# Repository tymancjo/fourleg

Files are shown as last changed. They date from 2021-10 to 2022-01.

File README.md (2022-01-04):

# FLR „Aron”

# Mk2 is on the way

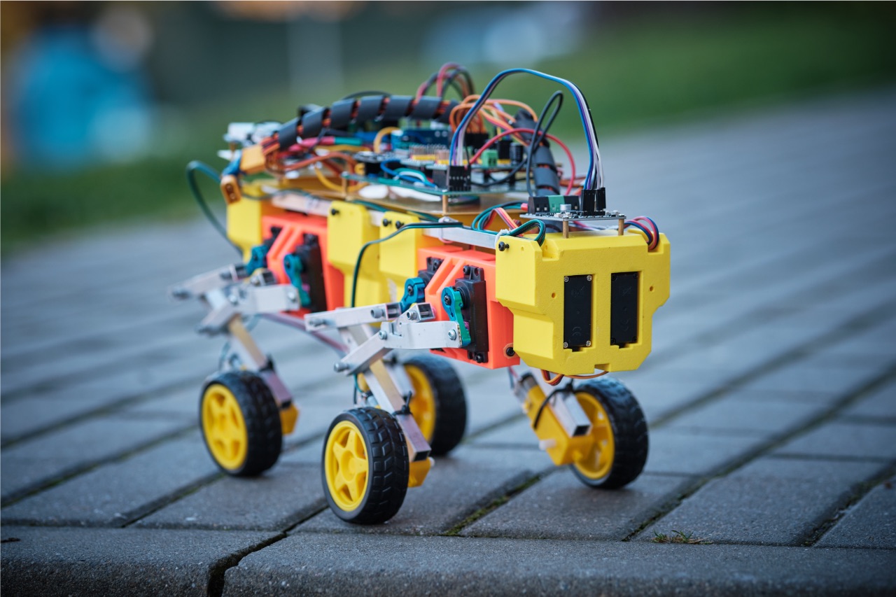
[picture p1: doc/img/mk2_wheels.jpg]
Aron Mk2
Currently a new version is in the development, hence all the code and data for the mk1 were moved ot the mk1 folder. 

## Mk2 idea

The main idea behind the mk2 is to add the 3th DOF for the leg. It is made by use of one additional servo for each leg. It is now heavily based on the 3d printed parts.

## Mechanical model

The - not so fully finished - 3d model made in Fusion 360 is available in the **3D_model** folder. It covers all the required geometry in the form that was used for the build.

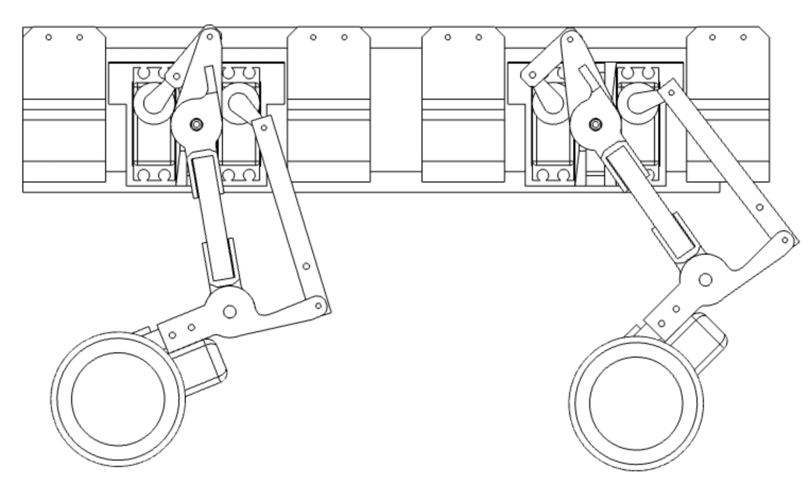
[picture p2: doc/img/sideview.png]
Aron sketch


However some leg parts need to be printed as they are and as a mirrored ones - for the other side.
As this project will move forward - the model will be updated to the full one.

Additionally all STL files (for both sides left and right) that were used for printing and build are in the **3D_model/STL** folder.

## General BOM

To build the Aron the following components are needed:

- The 3D printed parts

  - 2x End Mount
  - 2x Middle Support
  - 4x Leg Bracket
  - Knee LR x2
  - Motor R x2
  - Motor L x2
  - Top LR x2

- The ESP32 as a main control unit
- 2x PCA9685 to control the servos
- DC/DC converter for powering servo
- DC/DC converter for the electronic
- 2 channel H control for the DC motors
- BLT 05 BlueTooth unit

## The firmware

The main piece of software that is controlling the Aron is the **mk2_firmware** located in the **Arduino** folder.

## The interface

The Aron Mk2 in basic level can be controlled by the set of serial commands.
Those can be sent to the ESP32 main UART via either the USB connection of the module or via the used BT module.

For the convenience and ease of use additional layer in form of Web Control Interface is added. It is made out of two main interfaces - the Jog and the WebSerial.

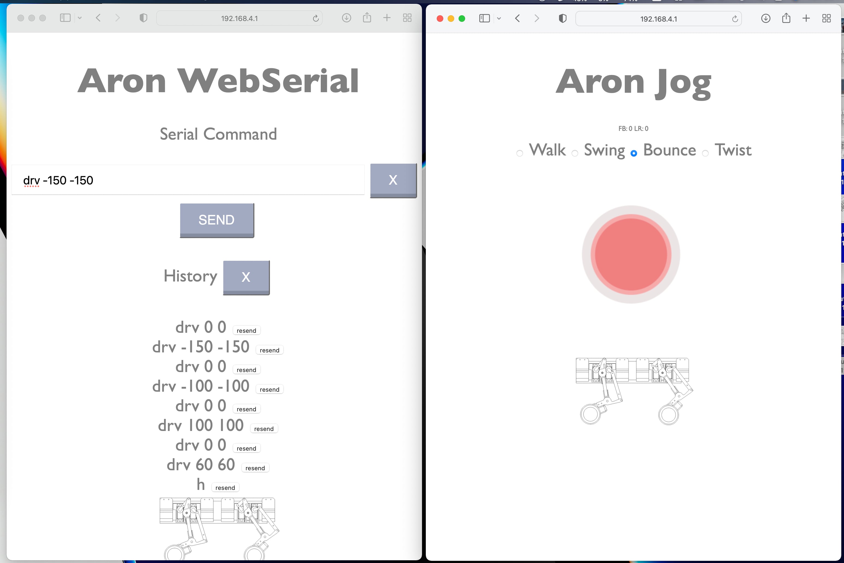
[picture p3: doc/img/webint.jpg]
web interfaces


### The Aron Jog

This interface is aimed for a real time remote control and allows to use the on screen joy to set live the behavior for:

- Walking around
- Swinging front and sideways
- Bounce up down
- Twist around.

This interface is available under:

> http://ARON_PI/

### The WebSerial

This is a basic web to serial transciver.
Works the same way as sending the serial commands directly via UART or BLE. Just is is available a sa webpage under:

> http://ARON_IP/serial

## Available Commands

At this stage the supported commands are:

- test // run the simple test sequence - just moves all servos in loop.
- power // toggle the power out
- show // displaying back the current angles of all servos

- h // resetting the servos to home position
- reset // resetting the servos home to initial position - but no move make
- ramp XXX // set up the ramp value input as 990 gives 0.99 ramp etc.

- circ XX YY // moving front back (XX) left right(YY) by 2 arguments
- move // triggering to make move to current incremental set
- up FF BB // lowering or rising front (FF) and back (BB) legs by given value (-40 to 40)
- leg L FF UP 0 // set data for single leg incremental model move - L leg number (1,2,3 or 4)
- drv LLL RRR // move the wheels by 2 params in range -255 to 255 (0 is strop) for Left (LLL) and Right (RRR) wheels
- s // full stop for wheels
- twist TT // twist - to make twisted pose - param in range -50 to 50
- walk // the sudo walk command
- w // the sudo walk command
- fake // to test the fake serial data

## Lastly:

> This is a work in progress project...

If you are interested please take a look at the vide playlist:
[YouTube Playlist](https://www.youtube.com/watch?v=CJRxDc_nvHY&list=PL9g9iwA2sCQyebAMLQ3WOS7w4_cqAUxdq)

#

#

# Original info about Aron Mk1

## Intro

FLR as Four Leg Robot - is a hobby project aimed for experimenting with the idea of simple and affordable four leg robot build. It’s a playground for self study of the basic ideas of kinetic, stability and more.

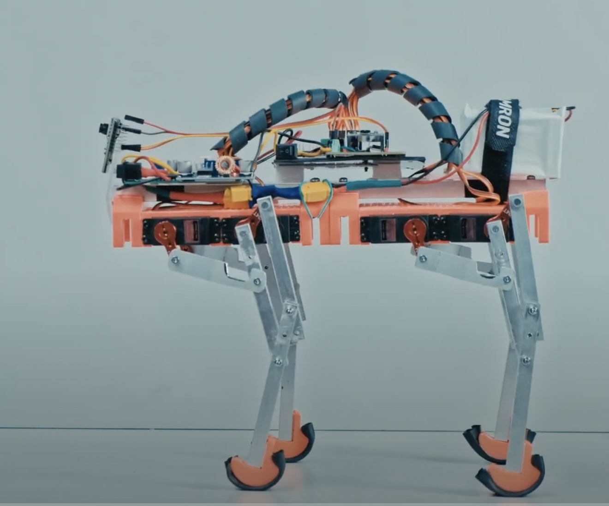
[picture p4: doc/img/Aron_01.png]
Aron


## More info

There is a set of videos - mostly in polish abut Aron and other robotic projects of mine.

YT (https://www.youtube.com/watch?v=iG_khF_uAIs&list=PL9g9iwA2sCQyebAMLQ3WOS7w4_cqAUxdq)

## Hardware

Hardware is based on the generally available parts and some simple 3D prints. The 3D model made in Autodesk Fusion 360 is available to download in the „Mechanical_Model” folder of this directory.

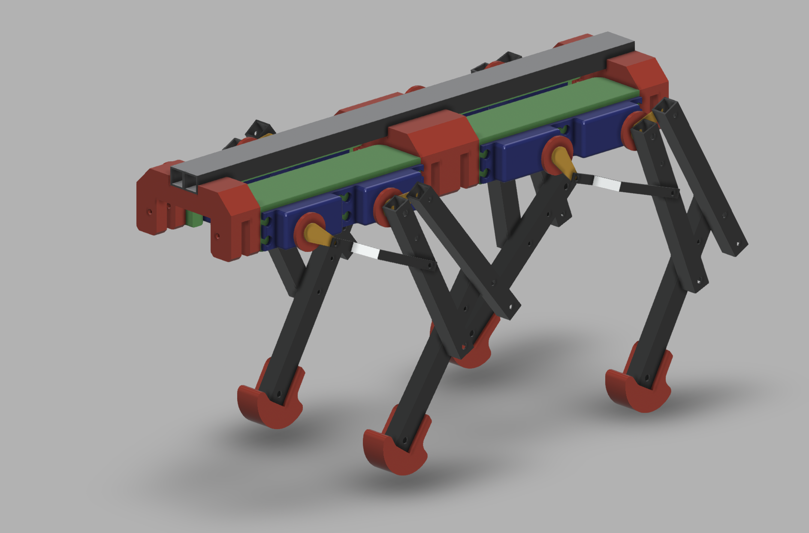
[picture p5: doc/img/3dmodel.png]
3D model


[fourleg/Mechanical_Model at main · tymancjo/fourleg · GitHub](https://github.com/tymancjo/fourleg/tree/main/Mechanical_Model)

And a 3d visualization under the link:
https://gmail1957699.autodesk360.com/g/shares/SH35dfcQT936092f0e43c23261b81addf43c

Beside the mechanicals the main components are MG995 180 degree servos (or in general any servo of the similar size and torque) , the PCA9685 16-Channel 12-bit PWM/Servo Driver to drive them and and esp32 as a main controller of the system. But the main controller role can be covered as well by Arduino board of generally any kind.

Power source is made of the 2S2P set of 18650 Li-Ion cells with appropriate BMS system followed by 2 independent DC/DC converters that are stabilizing the voltage at 5V for servos (the V+ power on the PCA9685) and another 5V for the esp32.

In the prototype unit additionally an esp32cam is installed enabling some experiments possibility with simple computer vision. However it’s not a crucial element of the system.

## Software

The software is created in the Arduino IDE environment and utilize the supporting libraries from Adafruit and other ESP32 related ones.
The main firmware file is the „esp32_servo_from_uart_WiFi” sketch located in the Arduino folder.

[fourleg/Arduino at main · tymancjo/fourleg · GitHub](https://github.com/tymancjo/fourleg/tree/main/Arduino)

Separate software is available for the esp32cam module - and it is based on the available esp32cam example sketch delivered with the word manager resources.

Additionally some python helper programs are available - mostly used for plying around with preparing Aron poses and move sequences.

## Usage

There are two main ways to control the Aron behavior.
Firstly by the webpage.

### Webpage interface

When powered up the esp32 main unit setup a WiFi access point by a name BB.LAB.ARON and pass 123456789 (yeap! the super secure one). When connected to this network - an webpage is available under 192.168.1.1 IP address from where the pre-programmed behavior can be controlled by use of buttons.
It’s extreakly simple interface and shall be quite self explanatory.

### Serial (UART)

The other way of control is via the UART (serial port) communication to the main esp32. The transmission is set up tu go with the 115200 baud rate. But all of this can be modified in the firmware.

The way to send orders is to use the following string scheme:

> <C,s1,s2,s3,s4,s5,s6,s7,s8>

Where:
C - is the command id
And the s1 to s8 are parameters.

The main commands are:
42 - makes the servos set up to the given angles where s1 to s8 are servo angles.

44 - recall one of the stored positions, where s1 is the number of position (counting from 0), s2 to s8 need to be set to some value (any).

46 - plays saved sequence, where s1 is the sequence number, and the s2 is number of repetition (1 to 20). S3 to s8 need to be set to any number.

55 - saves the servos as new stored position taking the given angles where s1 to s8 are servo angles.

#### Servos numbering

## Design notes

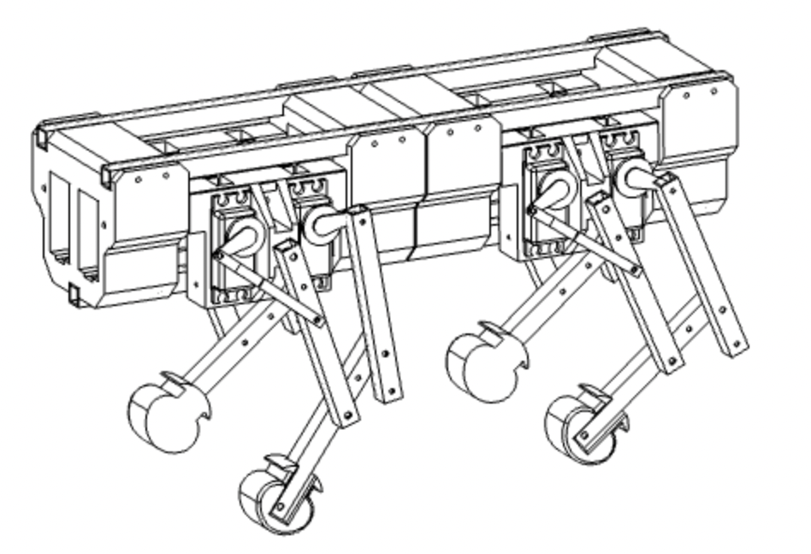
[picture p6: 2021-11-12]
Python/img/aronmk2.png

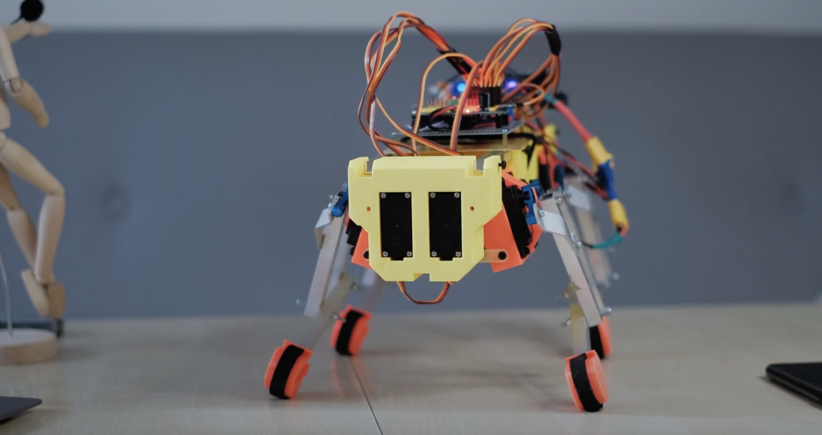
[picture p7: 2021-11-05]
doc/img/mk2.png

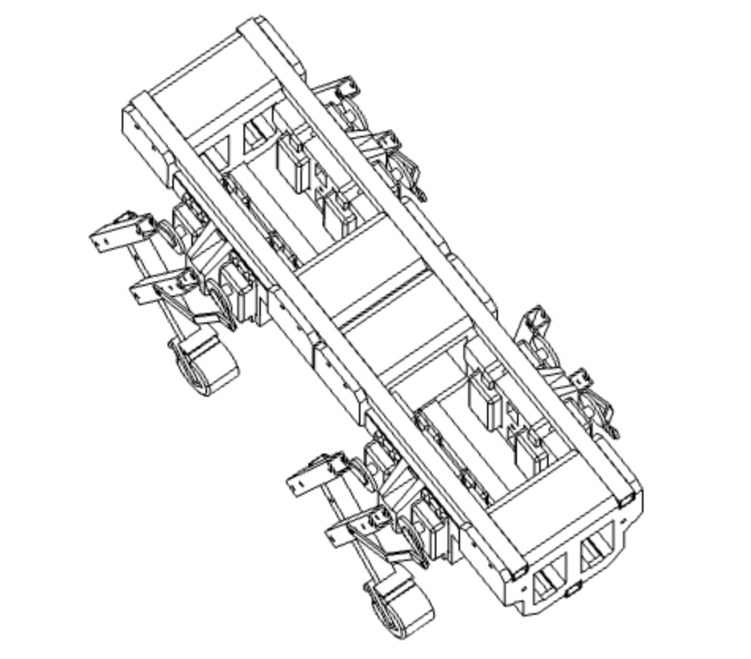
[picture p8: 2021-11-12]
Python/img/aronmk2T.png

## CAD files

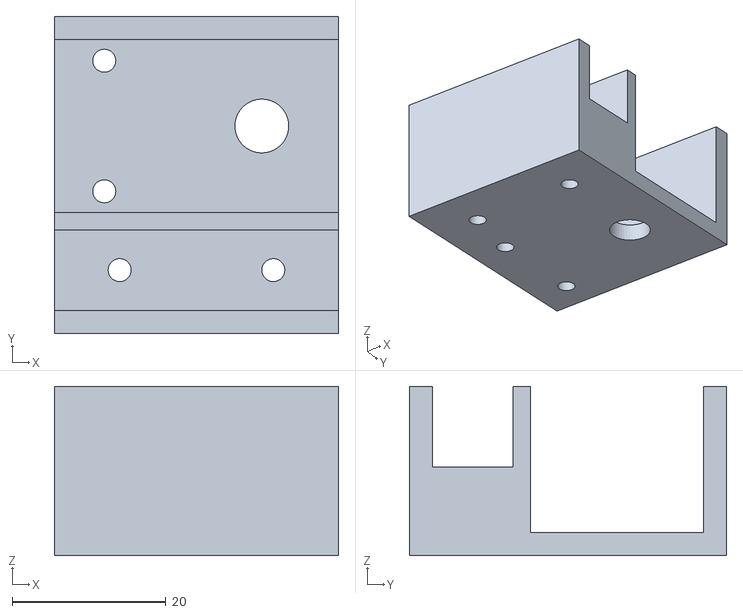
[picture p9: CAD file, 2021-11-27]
3D_model/STL/mk2_motor_L_2szt.stl
37.0 x 41.2 x 22.0

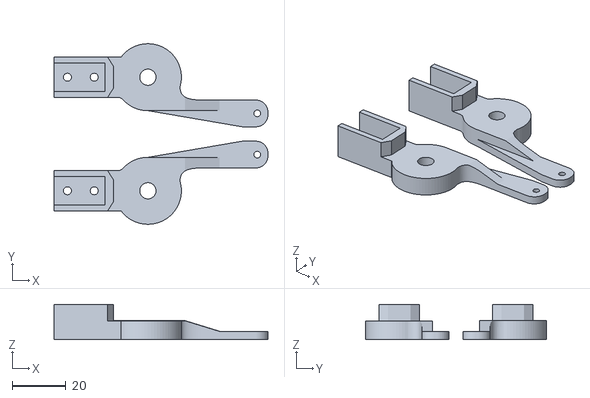
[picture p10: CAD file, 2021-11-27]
3D_model/STL/mk2_knee_LR_po_2szt.stl
79.8 x 67.3 x 13.1

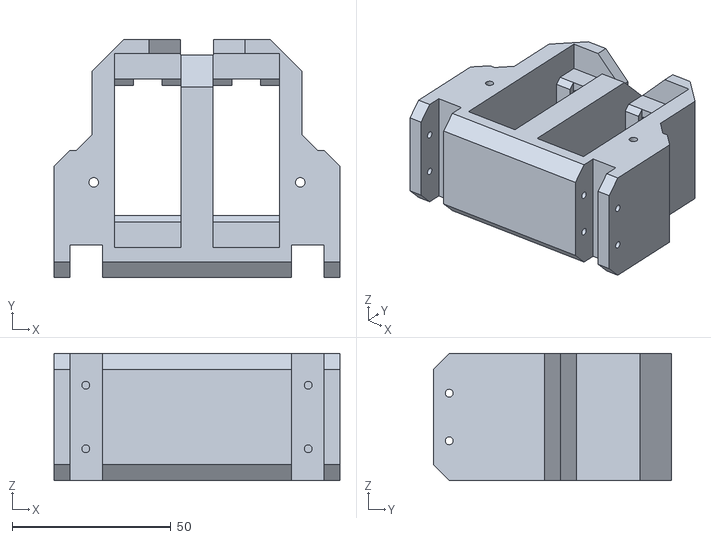
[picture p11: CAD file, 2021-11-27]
3D_model/STL/AronMk2EndMount_2szt.stl
90.0 x 75.0 x 40.0

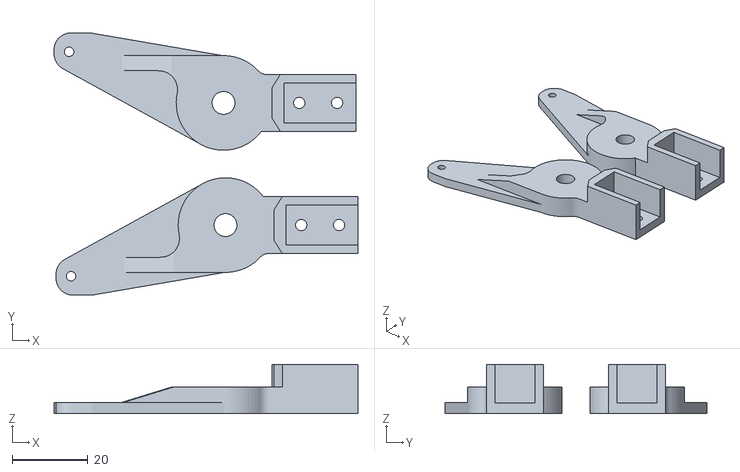
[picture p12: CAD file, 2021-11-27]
3D_model/STL/mk2_top_LR_po_2szt.stl
80.3 x 69.3 x 13.0

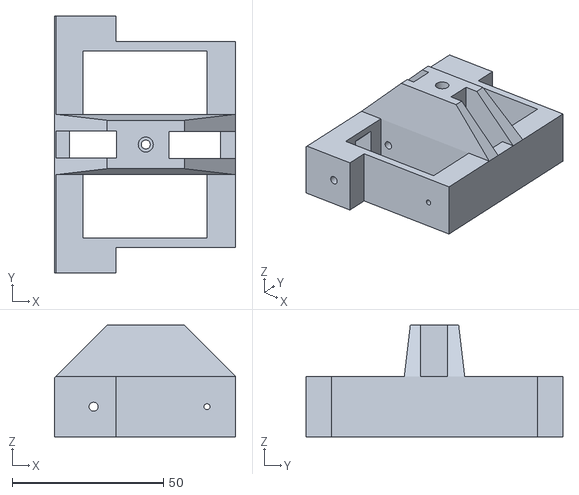
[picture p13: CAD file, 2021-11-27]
3D_model/STL/LegBracketMk2_V1_3szt.stl
60.0 x 85.0 x 37.0

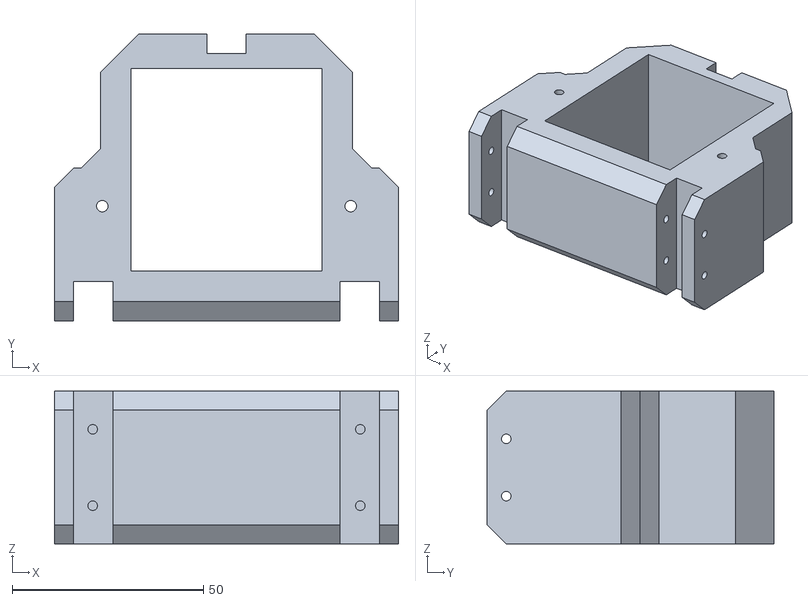
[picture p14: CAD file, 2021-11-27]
3D_model/STL/AronMk2MiddleSupport_2szt.stl
90.0 x 75.0 x 40.0

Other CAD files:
3D_model/STL/mk2_motor_R_2szt.stl
3D_model/Arom_Mk2_v1_v17.f3z
AronMk1/Mechanical_Model/flr_aron_mk1_v8.f3z

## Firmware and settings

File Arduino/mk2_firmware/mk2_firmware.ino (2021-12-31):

/*************************************************** 
  This is based on the example for our Adafruit 16-channel PWM & Servo driver
  Servo test - this will drive servos using  the PCA9685

  Pick one up today in the adafruit shop!
  ------> http://www.adafruit.com/products/815
  
  These drivers use I2C to communicate, 2 pins are required to  
  interface.

  Adafruit invests time and resources providing this open source code, 
  please support Adafruit and open-source hardware by purchasing 
  products from Adafruit!

  Written by Limor Fried/Ladyada for Adafruit Industries.  
  BSD license, all text above must be included in any redistribution
 ****************************************************/

#include <Wire.h>
#include <Adafruit_PWMServoDriver.h>

#include "SerialCommand.h"
SerialCommand sCmd; // The SerialCommand object

#include <WiFi.h>
#include <AsyncTCP.h>
#include <ESPAsyncWebServer.h>
// #include <ArduinoJson.h>

// to be able use filesystem
#include "FS.h"
#include "SPIFFS.h"

#include "secret.h"

// the credentials comes from the secret.h file
const char *ssid = SSIDs;
const char *password = PASSs;

// ********** Stuff for webservice *********

// Create AsyncWebServer object on port 80
AsyncWebServer server(80);
AsyncWebSocket ws("/ws");

void notifyClients()
{
  // I don't use anyting to be send back
}

void handleWebSocketMessage(void *arg, uint8_t *data, size_t len)
{
  AwsFrameInfo *info = (AwsFrameInfo *)arg;
  if (info->final && info->index == 0 && info->len == len && info->opcode == WS_TEXT)
  {
    data[len] = 0;
    command((char *)data);
  }
}

void onEvent(AsyncWebSocket *server, AsyncWebSocketClient *client, AwsEventType type,
             void *arg, uint8_t *data, size_t len)
{
  switch (type)
  {
  case WS_EVT_CONNECT:
    Serial.printf("WebSocket client #%u connected from %s\n", client->id(), client->remoteIP().toString().c_str());
    break;
  case WS_EVT_DISCONNECT:
    Serial.printf("WebSocket client #%u disconnected\n", client->id());
    break;
  case WS_EVT_DATA:
    handleWebSocketMessage(arg, data, len);
    break;
  case WS_EVT_PONG:
  case WS_EVT_ERROR:
    break;
  }
}

void initWebSocket()
{
  ws.onEvent(onEvent);
  server.addHandler(&ws);
}

String processor(const String &var)
{
  Serial.println(var);
  return "OK";
}

// ******************

// Setting up the PCA9685 units
Adafruit_PWMServoDriver pwm = Adafruit_PWMServoDriver(0x40);
Adafruit_PWMServoDriver pwm2 = Adafruit_PWMServoDriver(0x60);

// Depending on your servo make, the pulse width min and max may vary, you
// want these to be as small/large as possible without hitting the hard stop
// for max range. You'll have to tweak them as necessary to match the servos you
//// have!

#define SERVOMIN 170  // This is the 'minimum' pulse length count (out of 4096)
#define SERVOMAX 495  // This is the 'maximum' pulse length count (out of 4096)
#define SERVO_FREQ 50 // Analog servos run at ~50 Hz updates

// setting up the variabes for the servos
uint8_t servonum = 0;
const uint8_t servos = 16;
uint8_t servo_delay = 20;
uint8_t servos_steps_amount = 30;

// float servo_zero[servos]    = {   90,90,90,90,  90,90,90,90,  90,90,90,90,  90,90,90,90 };
// float servo_target[servos]  = {   90,90,90,90,  90,90,90,90,  90,90,90,90,  90,90,90,90 };
// float servo_home[servos]    = {   90,90,90,90,  90,90,90,90,  90,90,90,90,  90,90,90,90 };

float servo_zero[servos] = {90, 90, 90, 90, 90, 90, 90, 90, 110, 70, 110, 70, 90, 90, 90, 90};
float servo_target[servos] = {90, 90, 90, 90, 90, 90, 90, 90, 110, 70, 110, 70, 90, 90, 90, 90};
float servo_home[servos] = {90, 90, 90, 90, 90, 90, 90, 90, 110, 70, 110, 70, 90, 90, 90, 90};
bool servo_inverse[servos] = {0, 0, 1, 1, 0, 0, 1, 1, 0, 0, 1, 1, 0, 0, 0, 0};

// for making the incremental model
float servo_up[servos] = {0, 0, 0, 0, 0, 0, 0, 0, 0, 0, 0, 0, 0, 0, 0, 0};
float servo_side[servos] = {0, 0, 0, 0, 0, 0, 0, 0, 0, 0, 0, 0, 0, 0, 0, 0};
float servo_fb[servos] = {0, 0, 0, 0, 0, 0, 0, 0, 0, 0, 0, 0, 0, 0, 0, 0};
float servo_lr[servos] = {0, 0, 0, 0, 0, 0, 0, 0, 0, 0, 0, 0, 0, 0, 0, 0};
float servo_legs[servos] = {0, 0, 0, 0, 0, 0, 0, 0, 0, 0, 0, 0, 0, 0, 0, 0};

float servo_current[servos] = {150, 90, 150, 90, 150, 90, 150, 90, 90, 90, 90, 90, 0, 0, 0, 0};
float servo_ramp[servos];
float servo_step[servos] = {2, 2, 2, 2, 2, 2, 2, 2, 2, 2, 2, 2, 2, 2, 2, 2};

bool move_done = false;
bool in_loop = false;
bool in_linear = true;
int waiting = 0;

unsigned long now = millis();
unsigned long last = millis();
unsigned long last_step = millis();
unsigned long idle_time = millis();
unsigned long rand_sequence_time = millis();
int idle_moves = 0;
int idle_delay = 15000;
bool use_random = true;
bool in_random_sequence = false;
bool last_rand = false;
bool last_rand_walk = true;
bool last_rand_walk2 = true;

#define LEDPIN 2
#define POWEROUT 12

#define M1A 33
#define M1B 25
#define M2A 26
#define M2B 27

// #define DEBUG
#ifdef DEBUG
#define DEBUG_PRINT(x) Serial.print(x)
#define DEBUG_PRINTLN(x) Serial.println(x)
#else
#define DEBUG_PRINT(x)
#define DEBUG_PRINTLN(x)
#endif

bool power = false;

void setup()
{
  //  Serial.begin(115200);
  Serial.begin(9600);
  Serial.println("Aron mk2 Firmware System");
  pinMode(LEDPIN, OUTPUT);
  pinMode(POWEROUT, OUTPUT);

  // Preparing the PWM channels for the motors
  ledcAttachPin(M1A, 0); // assign a led pins to a channel
  ledcAttachPin(M1B, 1); // assign a led pins to a channel
  ledcAttachPin(M2A, 2); // assign a led pins to a channel
  ledcAttachPin(M2B, 3); // assign a led pins to a channel

  ledcSetup(0, 4000, 8); // 12 kHz PWM, 8-bit resolution
  ledcSetup(1, 4000, 8); // 12 kHz PWM, 8-bit resolution
  ledcSetup(2, 4000, 8); // 12 kHz PWM, 8-bit resolution
  ledcSetup(3, 4000, 8); // 12 kHz PWM, 8-bit resolution

  digitalWrite(POWEROUT, power);

  // Setup callbacks for SerialCommand command

  sCmd.addCommand("test", runTest);       // run the  test sequence - just moves all servos in loop.
  sCmd.addCommand("back", runBack);       // run the  test sequence - just moves all servos in loop.
  sCmd.addCommand("save", saveStep);      // adding current position as new step in selected sequence
  sCmd.addCommand("del", delLastStep);    // removing last step from given sequence
  sCmd.addCommand("power", togglePower);  // toggle the power out
  sCmd.addCommand("show", showAngles);    // displaying back the current angles of all servos
  sCmd.addCommand("write", saveToFile);   // saving the sequences to file
  sCmd.addCommand("read", loadFromFile);  // load the sequences form file
  sCmd.addCommand("load", loadFromFile2); // load the sequences form file

  sCmd.addCommand("h", makeHoming);   // ressetting the servos to home position
  sCmd.addCommand("reset", makeZero); // ressetting the servos home to initial position - but no move make
  sCmd.addCommand("ramp", setRamp);   // set up the ramp value input as 990 gives 0.99 ramp etc.

  sCmd.addCommand("circ", makeCircle); // moving front back left right by 2 arguments
  sCmd.addCommand("move", makeMove);   // triggering to make the move to current incremental set
  sCmd.addCommand("up", makeUp);       // adding the value to the homing of the up/dn servos
  sCmd.addCommand("side", makeSide);   // the left right leveling
  sCmd.addCommand("leg", moveLeg);     // set data for single leg incremental model move
  sCmd.addCommand("drv", driveWheels); // move the wheels by 2 params
  sCmd.addCommand("s", allStop);       // full stop for wheels
  sCmd.addCommand("twist", makeTwist); // twist - to make a turning - experimental
  sCmd.addCommand("walk", makeWalk);   // the sudo walk command
  sCmd.addCommand("w", makeWalk);      // the sudo walk command
  sCmd.addCommand("look", lookAround); // looking around in LR TD

  sCmd.addCommand("fake", fakeData);       // to test the fake serial data
  sCmd.addCommand("mode", toogleMmode);    // toggle the interpoloation mode
  sCmd.addCommand("random", toogleRandom); // toggle random behaviour
  sCmd.addCommand("step", setStepSize);    // to set the single step size in degrees
  sCmd.addCommand("delay", setDelay);      // to set the each loop servos delay

  sCmd.addCommand("setraw", setAllServosRaw); // kind of the backdoor function to set all servos
  sCmd.addCommand("list", listSequences);     // listing the current sequences to serial port

  // sCmd.addCommand("s", setServo);             // set a single servo command
  // sCmd.addCommand("d", setServoDelta);        // set a single servo by delta angle command
  // sCmd.addCommand("ad", setAllServosDelta);   // move all by individual deltas
  // sCmd.addCommand("adh", setAllServosDeltaHome);  // move all by individual deltas from home position

  sCmd.setDefaultHandler(unrecognized); // Handler for command that isn't matched  (says "What?")

  // preparing the inital positions.
  for (int k = 0; k < servos; k++)
  {
    set_servo(k, servo_current[k]);
    servo_ramp[k] = 0.95;
  }

  // kicking off the PCA units
  pwm.begin();
  pwm2.begin();

  /*
   * In theory the internal oscillator (clock) is 25MHz but it really isn't
   * that precise. You can 'calibrate' this by tweaking this number until
   * you get the PWM update frequency you're expecting!
   * The int.osc. for the PCA9685 chip is a range between about 23-27MHz and
   * is used for calculating things like writeMicroseconds()
   * Analog servos run at ~50 Hz updates, It is importaint to use an
   * oscilloscope in setting the int.osc frequency for the I2C PCA9685 chip.
   * 1) Attach the oscilloscope to one of the PWM signal pins and ground on
   *    the I2C PCA9685 chip you are setting the value for.
   * 2) Adjust setOscillatorFrequency() until the PWM update frequency is the
   *    expected value (50Hz for most ESCs)
   * Setting the value here is specific to each individual I2C PCA9685 chip and
   * affects the calculations for the PWM update frequency. 
   * Failure to correctly set the int.osc value will cause unexpected PWM results
   */
  pwm.setOscillatorFrequency(27000000);
  pwm.setPWMFreq(SERVO_FREQ); // Analog servos run at ~50 Hz updates

  pwm2.setOscillatorFrequency(27000000);
  pwm2.setPWMFreq(SERVO_FREQ); // Analog servos run at ~50 Hz updates

  // checking the file system
  if (!SPIFFS.begin(true))
  {
    Serial.println("An Error has occurred while mounting SPIFFS");
    return;
  }

  // Preparing static IP adress
  IPAddress local_ip0(192, 168, 0, 123);
  IPAddress gateway0(192, 168, 0, 1);
  IPAddress subnet0(255, 255, 255, 0);

  // Connect to Wi-Fi
  if (!WiFi.config(local_ip0, gateway0, subnet0))
  {
    Serial.println("STA Failed to configure");
  }

  WiFi.begin(ssid, password);
  int wifitrys = 0;
  while (WiFi.status() != WL_CONNECTED)
  {
    delay(1000);
    Serial.println("Connecting to WiFi..");
    wifitrys++;

    if (wifitrys > 7)
      break;
  }
  delay(300);

  // if not connected - making own AP
  if (WiFi.status() != WL_CONNECTED)
  {
    WiFi.disconnect();

    delay(1000);
    // setting up self WiFi
    const char *ssid2 = "BB.LAB.ARON";
    const char *password2 = "123456789";

    /* Put IP Address details */
    IPAddress local_ip(192, 168, 1, 1);
    IPAddress gateway(192, 168, 1, 1);
    IPAddress subnet(255, 255, 255, 0);

    Serial.print("Setting AP (Access Point)…");
    WiFi.softAP(ssid2, password2);
    WiFi.softAPConfig(local_ip, gateway, subnet);
    delay(300);
    Serial.println(WiFi.softAPIP());
  }
  else
  {
    // Print ESP Local IP Address
    Serial.println(WiFi.localIP());
  }

  initWebSocket();

  // Route for root / web page
  server.on("/", HTTP_GET, [](AsyncWebServerRequest *request)
            { request->send(SPIFFS, "/index.html", "text/html"); });

  server.on("/serial", HTTP_GET, [](AsyncWebServerRequest *request)
            { request->send(SPIFFS, "/serial.html", "text/html"); });

  server.on("/img", HTTP_GET, [](AsyncWebServerRequest *request)
            { request->send(SPIFFS, "/aronmk2.jpg", "image/jpeg"); });

  // Start server
  server.begin();

  Serial.print("Starting up");
  for (int k = 0; k < 21; k += 4)
  {
    digitalWrite(LEDPIN, HIGH);
    Serial.print(".");
    delay(400 - k * 20);
    digitalWrite(LEDPIN, LOW);
    delay(400 - k * 20);
  }
  Serial.println();
  digitalWrite(LEDPIN, HIGH);
  loadFromFile2(); // loading the stored in file move sequences
}

// simple loop moving test - usefull for hardware verification.
const int sequences = 10; // the total numbeer of available sequences
const int max_steps = 30; // the max number of steps in each sequence
int test_step = 0;        // the step counter for seq playback
uint8_t set_sequence = 0; // the selected sequence for playback
int seq_direction = 1;    // its 1 or -1 is the step by which the seq is proceed
uint8_t test_steps[sequences] = {2, 0, 0, 0, 0, 0, 0, 0, 0, 0};
uint8_t seq_repetitions = 50;
uint8_t this_repetitions = 0;

// this is the hardcoded move sequence used for walk command
uint8_t test_pos[sequences][max_steps][servos] = {
    {// first sequence
     {70, 70, 110, 110, 110, 110, 70, 70, 140, 80, 90, 40, 90, 90, 90, 90},
     {110, 110, 70, 70, 70, 70, 110, 110, 100, 40, 130, 80, 90, 90, 90, 90}}};

void loop()
{
  // marking current time
  now = millis();
  // making the read from serial
  sCmd.readSerial();
  // checking the `webSocket stuff
  ws.cleanupClients();

  // playing the storred sequence
  if (now > last_step + 100 && move_done && in_loop && test_steps[set_sequence] > 0 && this_repetitions < seq_repetitions)
  {
    last_step = now;
    idle_time = now;

    DEBUG_PRINT(set_sequence);
    DEBUG_PRINT(':');
    DEBUG_PRINT(test_step);
    DEBUG_PRINTLN();

    for (int s = 0; s < servos; s++)
    {
      servo_target[s] = test_pos[set_sequence][test_step][s];
    }
    test_step += seq_direction;
    move_done = false;
    getStepSize();

    if (test_step >= test_steps[set_sequence])
    {
      test_step = 0;
      this_repetitions++;
    }
    if (test_step < 0)
    {
      test_step = test_steps[set_sequence] - 1;
      this_repetitions++;
    }
  } // end of servo sequence play

  if (this_repetitions >= seq_repetitions)
  {
    drive(0, 0);
  }

  // checking for standing still too long
  if (now > idle_time + idle_delay && use_random)
  {
    uint8_t selector = random(0, 100);
    if (selector > 30)
    {
      idle_moves++;
      if (idle_moves < 10)
      {
        idle_delay = random(1000, 4000);
      }
      else
      {
        idle_delay = random(8000, 20000);
        idle_moves = 0;
      }

      int look_x = random(0, 40) - 20;
      int look_y = random(0, 60) - 15;
      char chars[32];

      sprintf(chars, "look %d %d\n", look_x, look_y);
      command(chars);
    }
    else if (selector > 20)
    {
      in_random_sequence = true;
      idle_delay = random(4000, 9000);
      rand_sequence_time = now;
      idle_time = now;

      if (last_rand_walk)
      {
        command("test 2\n");
      }
      else
      {
        command("back 2\n");
      }
      last_rand_walk = !last_rand_walk;
    }
    else if (selector > 10)
    {
      in_random_sequence = true;
      idle_delay = random(6000, 11000);
      rand_sequence_time = now;
      idle_time = now;

      if (last_rand_walk)
      {
        command("test 3\n");
      }
      else
      {
        command("back 3\n");
      }
      last_rand_walk2 = !last_rand_walk2;
    }
    else
    {
      // if selector is <10
      // we will turn l/r
      in_random_sequence = true;
      idle_delay = random(2000, 4000);
      rand_sequence_time = now;
      idle_time = now;
      if (last_rand)
      {
        command("w 0 110\n");
      }
      else
      {
        command("w 0 -110\n");
      }
      last_rand = !last_rand;
    }
  }

  // stoping random seq if active
  if (in_random_sequence && now > rand_sequence_time + idle_delay)
  {
    command("s\n");
    in_random_sequence = false;
    idle_delay = random(1000, 3000);
  }

  // making the servos moves - the main loop action
  if (now > last + servo_delay)
  {
    last = now;
    move_done = true;
    for (int s = 0; s < servos; s++)
    {

      // checking if need to move
      if (abs(servo_target[s] - servo_current[s]) > 1)
      {
        // if the servo is away more than a 1 degree we move
        move_done = false;
        if (in_linear)
        {
          // procedure for the linera move with constant step
          // figuring out the direction
          float the_step = 0.0;
          if (servo_current[s] < servo_target[s] - servo_step[s])
          {
            the_step = servo_step[s];
          }
          else if (servo_current[s] > servo_target[s] + servo_step[s])
          {
            the_step = -servo_step[s];
          }
          else
          {
            the_step = servo_target[s] - servo_current[s];
          }

          servo_current[s] += the_step;
        }
        else
        {
          servo_current[s] = servo_ramp[s] * servo_current[s] + (1 - servo_ramp[s]) * servo_target[s];
        }
        set_servo(s, servo_current[s]);
      }
      else
      {
        servo_current[s] = servo_target[s];
      }
    }
  }

} // loop

// Functions are placed in the separate file.
// Aron Mk2 firmware
// Functions file.

void listSequences()
{
  /*
  This function prints out all the sequences (beside the hardcoded 0)
  to the serial port as txt
  Is introduced to make the copy of saved in spiffs file data.
  */

  for (int seq = 1; seq < sequences; seq++)
  {
    Serial.print("Sequence ");
    Serial.println(seq);
    if (test_steps[seq] > 0)
    {
      for (int step = 0; step < test_steps[seq]; step++)
      {
        Serial.print("setraw ");
        for (int servo = 0; servo < servos; servo++)
        {
          Serial.print(test_pos[seq][step][servo]);
          Serial.print(" ");
        }
        Serial.println();
      }
      Serial.println();
    }
  }
}

void saveToFile()
{
  // conceptual idea how to write the sequences to the file
  // it's just a sudo code
  //
  // for sequence in sequnces:
  //     file.write(test_steps[sequence]) // writing down the numer of steps.
  //     for step in test_steps[sequence]:
  //         for s in test_pos[sequence][step]:
  //             file.write(test_pos[sequence][step][s])

  // let's open the file for writing
  File frame = SPIFFS.open("/frame.bin", "wb+");
  if (!frame)
  {
    Serial.println("file open failed");
  }
  else
  {
    Serial.println("file opened");
    Serial.printf("Start Position = %u \n", frame.position()); // Prints what position in the file we're in
    // since we open it we can now write it down
    for (byte seq = 1; seq < sequences; seq++)
    {
      // checking if there is anything to save...
      if (test_steps[seq] > 0)
      {
        frame.write(test_steps[seq]); // Saving the number of steps in seq.
        Serial.print("Test seq of: ");
        Serial.println(test_steps[seq]);
        for (byte st = 0; st < test_steps[seq]; st++)
        {
          for (byte ser = 0; ser < servos; ser++)
          {
            frame.write(test_pos[seq][st][ser]); // Saving the number of steps in seq.
          }
        }
      }
      else
      {
        Serial.println("Empty sequence..skip.");
      }
    }
    frame.close();
  }
}

void loadFromFile2()
{

  File frame = SPIFFS.open("/frame.bin", "rb");
  if (!frame)
  {
    // Serial.println("file open failed");
  }
  else
  {
    size_t filesize = frame.size(); //the size of the file in bytes
    if (filesize > 0)
    {
      int pos = 1;
      int load_seq;

      while (pos < filesize)
      {
        uint8_t this_read;
        frame.read(&this_read, sizeof(this_read));
        if (this_read > 0 && (filesize - pos) > this_read * 16)
        {
          load_seq++; // setting the sequence to load.
          test_steps[load_seq] = (uint8_t)this_read;

          // if the read byte shows some steps we continue
          for (byte step = 0; step < this_read; step++)
          {
            // we read the amount of steps that was in the initial byte
            // and we do it for each servo
            for (byte servo = 0; servo < servos; servo++)
            {
              uint8_t servo_read;
              frame.read(&servo_read, sizeof(servo_read));
              test_pos[load_seq][step][servo] = (int)servo_read;
              pos++;
            }
          }
        }
        else
        {
          break;
        }
      }
    }
    frame.close();
  }
} // loadFromFile2

void loadFromFile()
{

  File frame = SPIFFS.open("/frame.bin", "rb");
  if (!frame)
  {
    Serial.println("file open failed");
  }
  else
  {
    Serial.println("file opened");
    size_t filesize = frame.size(); //the size of the file in bytes
    if (filesize > 0)
    {
      int pos = 1;
      int load_seq;

      while (pos < filesize)
      {
        uint8_t this_read;
        frame.read(&this_read, sizeof(this_read));
        if (this_read > 0 && (filesize - pos) > this_read * 16)
        {
          Serial.print("Set of steps:");
          Serial.println((int)this_read);
          load_seq++; // setting the sequence to load.
          test_steps[load_seq] = (uint8_t)this_read;

          // if the read byte shows some steps we continue
          for (byte step = 0; step < this_read; step++)
          {
            // we read the amount of steps that was in the initial byte
            // and we do it for each servo
            Serial.print(step);
            Serial.print(": ");

            for (byte servo = 0; servo < servos; servo++)
            {
              uint8_t servo_read;
              frame.read(&servo_read, sizeof(servo_read));
              Serial.print((int)servo_read);
              Serial.print(", ");

              test_pos[load_seq][step][servo] = (int)servo_read;
              pos++;
            }
            Serial.println();
          }
        }
        else
        {
          break;
        }
      }
    }
    frame.close();
  }
}
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

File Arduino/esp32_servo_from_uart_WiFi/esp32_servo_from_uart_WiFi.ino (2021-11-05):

// # FLR - reciver module
#include <Arduino.h>
#include <SPI.h>
#include <Adafruit_PWMServoDriver.h>
// Load Wi-Fi library
#include <WiFi.h>
#include <WebServer.h>

// Stuff for serial communication use
bool newData = false;
bool fakeData = false;
const byte numChars = 48;
char receivedChars[numChars];
char tempChars[numChars];
// variables to hold the parsed data
char messageFromPC[numChars] = {0};
// global variables to keep the received data
int param[8];
int command;

// Stuff for wifi
// Replace with your network credentials
const char* ssid     = "BB.LAB.ARON";
const char* password = "123456789";

/* Put IP Address details */
IPAddress local_ip(192,168,1,1);
IPAddress gateway(192,168,1,1);
IPAddress subnet(255,255,255,0);

// Set web server port number to 80
WebServer server(80);

// for the second uart
#define RXD2 13
#define TXD2 12


// kicking of the pwm module definition
// called this way, it uses the default address 0x40
Adafruit_PWMServoDriver pwm = Adafruit_PWMServoDriver();

// defining the values used for PWM servo control
// those were selected after experiment with the real used hw servos
// #define SERVOMIN 160  // This is the 'minimum' pulse length count (out of 4096)
// #define SERVOMAX 505  // This is the 'maximum' pulse length count (out of 4096)
#define SERVOMIN 170  // This is the 'minimum' pulse length count (out of 4096)
#define SERVOMAX 495  // This is the 'maximum' pulse length count (out of 4096)
#define SERVO_FREQ 50 // Analog servos run at ~50 Hz updates

// for servos attached to the PWM module
// initial reset position
const int pos0 = 0;
// total servo canals count
const int servo_count = 16;
float ramp = 0.95;

uint8_t servos_pos[servo_count] = {90};

float servos_curr[servo_count] = {90};
bool servos_interpolate[servo_count] = {true};

unsigned long now;
unsigned long last = 0;

// Stuff for pre-programmed poses
const int poses_rows = 20;

int poses[poses_rows][8] = {
  {180, 163, 10, 17, 180, 153, 0, 17},
  {148, 51, 42, 129, 148, 41, 32, 129},
  {64, 79, 126, 101, 64, 69, 116, 101},
  {180, 122, 10, 58, 64, 69, 116, 101},
  {148, 51, 42, 129, 148, 41, 0, 0},
  {148, 51, 42, 129, 180, 180, 32, 129}
};

String pose_names[poses_rows] = {
"LEZEC",
"JAMNIK",
"TROP",
"SIAD",
"Lapka L",
"Lapka R",
"Pos",
"Pos",
"Pos",
"Pos",
"Pos",
"Pos",
"Pos",
"Pos",
"Pos",
"Pos",
"Pos",
"Pos"
};

int total_poses = 6;

// handling the move sequences.
bool move_done = false;
bool in_sequence = false;
int sequence_nr = 0;
int sequence_rep = 1;
int sequence_crep = 0;
int sequence_step = 0;

const uint8_t max_sequences = 3;
const uint8_t max_steps = 30;
const uint8_t max_servos = 8;

String seq_names[max_sequences] = {
"BSSF Step",
"Drunk Master"
  };

int sequences[max_sequences][max_steps][max_servos] = 
{
    {
      {119,70,71,110,119,60,61,110},
      {119,70,44,118,119,60,61,110},
      {119,70,44,118,174,64,61,110},
      {119,70,44,118,112,108,61,110},
      {119,70,71,111,112,108,61,110},
      {119,70,71,111,112,108,74,68},
      {103,70,87,110,112,108,74,68},
      {103,70,87,110,150,84,30,86},
      {87,55,103,125,150,84,30,86},
      {87,55,103,125,112,76,68,94},
      {71,58,119,122,71,48,109,122},
      {139,39,119,122,71,48,109,122},
      {97,97,119,122,71,48,109,122},
      {76,83,119,122,110,40,109,122},
      {76,83,92,91,110,40,109,122},
      {76,83,92,91,83,68,109,122}
    },
    {
      
      {99,73,91,107,99,63,81,107},
      {109,83,81,97,109,73,36,136},
      {109,83,81,97,109,73,66,71},
      {93,59,97,121,93,49,66,71},
      {138,71,97,121,93,49,66,71},
      {101,108,97,121,93,49,66,71},
      {82,103,97,121,93,49,66,71},
      {82,103,97,121,135,56,66,71},
      {82,103,97,121,111,104,66,71},
      {83,59,107,121,83,49,97,121},
      {83,59,59,149,83,49,97,121},
      {83,59,107,121,83,49,97,121}
    },
    {
      {89,64,106,99,74,81,91,116},
      {74,81,91,116,89,64,106,99},
    }
};

// {109,83,81,97,109,73,71,97},

float ramps[max_steps];
uint8_t sequence_steps[max_sequences] = {15};

void setup()
{
  // kicking off serial
  Serial.begin(115200);
  Serial2.begin(115200, SERIAL_8N1, RXD2, TXD2);

  // Servos reset
  pwm.begin();
  pwm.setOscillatorFrequency(27000000);
  pwm.setPWMFreq(SERVO_FREQ); // Analog servos run at ~50 Hz updates
  delay(100);

  Serial.print("Resetting Servo: ");
  for (int i = 0; i < servo_count; i++)
  {
    servos_pos[i] = 90;
    servos_curr[i] = servos_pos[i];
    Serial.print(i);
    Serial.print(" ");
    Serial.println(servos_curr[i]);
    pwm.setPWM(i, 0, (int)map(servos_curr[i], 0, 180, SERVOMIN, SERVOMAX));
    delay(10);
  }
  delay(500);

  // Connect to Wi-Fi network with SSID and password
  Serial.print("Setting AP (Access Point)…");
  WiFi.softAP(ssid, password);
  WiFi.softAPConfig(local_ip, gateway, subnet);
  delay(100);

  server.on("/", handle_OnConnect);
  
  
  server.on("/p", handle_pose);

  server.on("/s", handle_sequence);

  server.on("/r", handle_ramp);
    
  server.onNotFound(handle_NotFound);
  
  server.begin();
  Serial.println("HTTP server started");

  // the sequences data

// the crazy dog step
  sequence_steps[0] = 16;
  sequence_steps[1] = 12;
  sequence_steps[2] = 2;

  for (int i=0; i < max_steps; i++){
    ramps[i] = 0.85;
    }
  
}
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

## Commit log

2021-10-03 working leg simulator
2021-10-07 Working on the IK model, adding UART to simulator
2021-10-18 making the real repo
    [flr_aron_mk1_v8.f3z]
2021-10-30 Starting work on Aron Mk2, all Mk1 files put to folder
    [flr_aron_mk1_v8.f3z]
2021-10-30 1st servo solved for mk2 leg
    [ik_develop.py]
2021-11-06 Working on uart comunication
2021-11-09 Making startup sequence with led
2021-11-11 adding more functionality to uart controls
2021-11-12 Working on uarc control - adding incremental commands and by leg moves
2021-11-13 Adding wheels and support for it
2021-11-20 Reeleasing the more less working prototype version
2021-11-27 Updating the readme
    [Arom_Mk2_v1_v17.f3z, AronMk2EndMount_2szt.stl, AronMk2MiddleSupport_2szt.stl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]
2021-12-03 added updated look command, and linear servo interpolation mode plus more
2021-12-27 Added reverse sequences play
    [mk2_firmware.ino]
